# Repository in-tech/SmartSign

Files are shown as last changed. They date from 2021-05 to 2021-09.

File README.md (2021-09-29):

# SmartSign
A battery powered e-Paper sign for conference rooms.

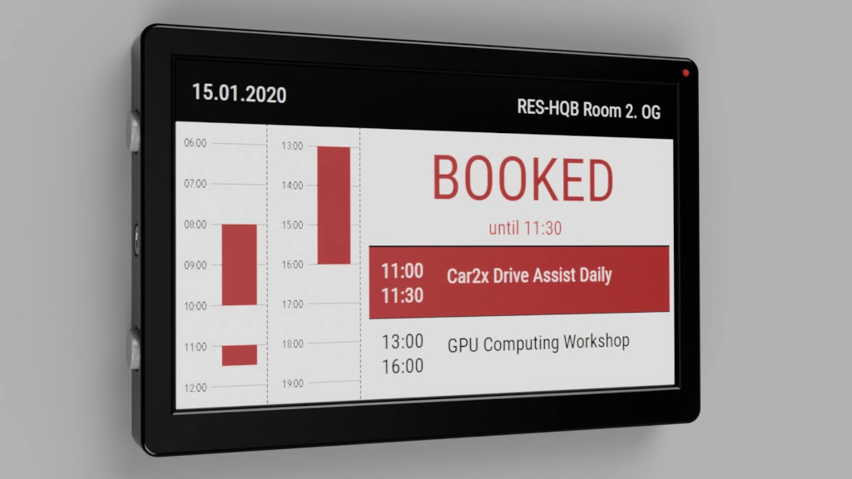
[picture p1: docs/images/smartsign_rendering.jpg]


## Device-Frame
The shell components are optimized for FDM printing in PLA with 0.2 mm layer height.

STL-files:
* [Backplate.stl](stl_files/Backplate.stl)
* [ButtonSpacer.stl](stl_files/ButtonSpacer.stl)
* [Frame.stl](stl_files/Frame.stl)
* [Inlay.stl](stl_files/Inlay.stl)

## Electronics
The hardware is based on of the shelf components and requires no custom PCB designs:
* DFRobot FireBeetle ESP32 IOT Microcontroller
* Waveshare 7.5inch e-Paper B V1 (640x384)
* 3000 mAh LiPo Battery
* RFID RC522 Reader to read Mifare S50 keycards for administration and authorization
* Mechanical endstop to wake ESP when card is inserted
* 3mm red LED with 47µF Capacitor and N-Channel FET to keep LED state when ESP is in deep sleep
* 2x tactile switch buttons (12x12x7.3mm)
* Resistors: 1x 330 Ohm, 3x 22K-Ohm, 1x 32K-Ohm, 2x 100K-Ohm
  
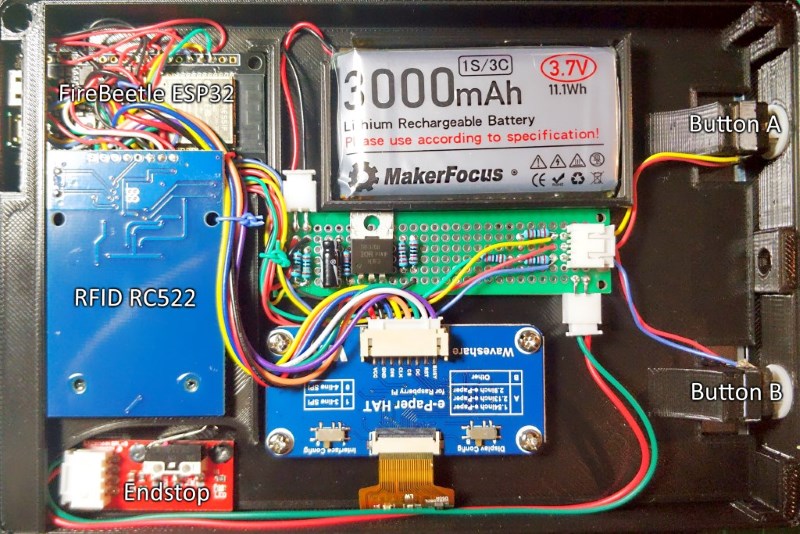
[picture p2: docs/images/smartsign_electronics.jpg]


How the components are interconnected, is documented here: [smartsign_schematic.pdf](docs/smartsign_schematic.pdf)

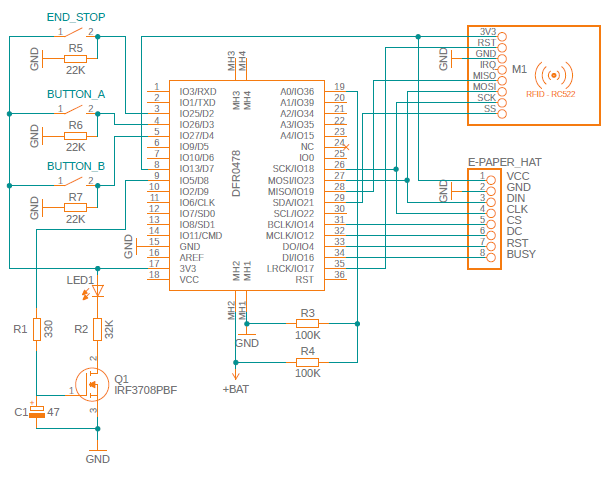
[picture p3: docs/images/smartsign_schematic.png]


## Firmware
The firmware is written in C++ and based on PlatformIO. Before you can build the project, you have to create a settings file by renaming the file [`.\lib\SmartSign\GlobalSettings.h.default`](lib/SmartSign/GlobalSettings.h.default) to `.\lib\SmartSign\GlobalSettings.h`. 

In `GlobalSettings.h` change the `ADMIN_CARD_ID` value to match the id of the keycard you want to use to enter the administration mode. All other parameters in this file are default values and can be changed during runtime in the setup mode via web-interface.

## Administration-Mode
You can enter the administration mode, by inserting the **administration keycard** into the cardslot:

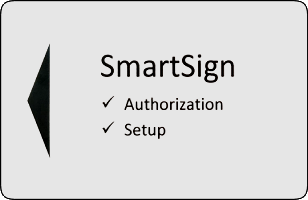
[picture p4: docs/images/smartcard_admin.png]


The administration screen provides information about the current battery voltage, WiFi status and NTP time. When the battery voltage falls below 3.6 volt you should consider recharging the device.

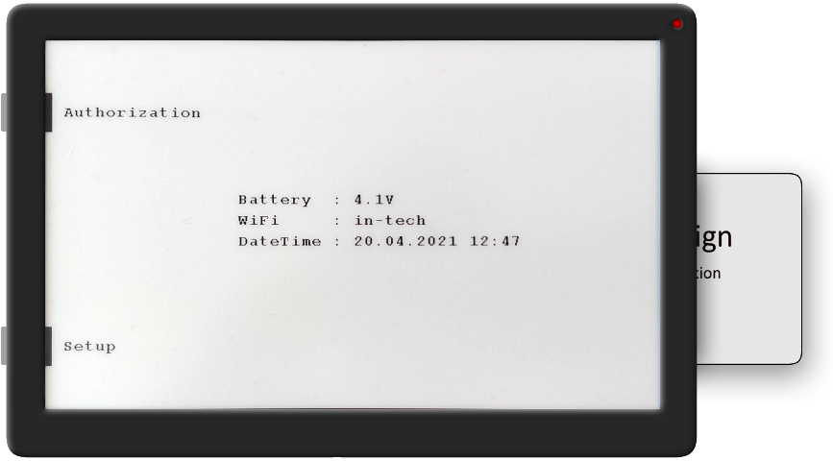
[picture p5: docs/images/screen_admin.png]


## Setup-Mode
You can enter the setup mode by pressing button B in the administration mode. In this mode, the SmartSign creates a temporary WiFi hotspot with a random name and random password. Whe connecting to this WiFi with your smartphone or computer, you gain access to a property page where you can change the settings specified in [`.\lib\SmartSign\GlobalSettings.h`](lib/SmartSign/GlobalSettings.h.default). The most important settings are the WiFi credentials, the name of the schedule and the Azure client and tenant ids (more on this [here](https://docs.microsoft.com/en-us/graph/tutorials/dotnet-core?view=graph-rest-beta&tutorial-step=2)). 

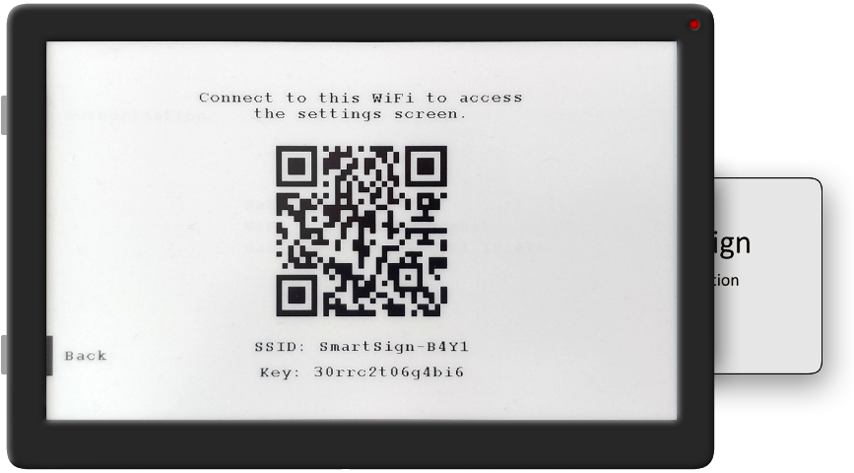
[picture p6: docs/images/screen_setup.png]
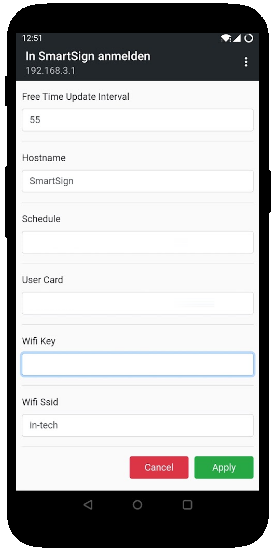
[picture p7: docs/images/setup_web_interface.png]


## Authorization-Mode
Before the SmartSign can show schedules of your outlook calendar, you have to authorize the device to access you calendar. You can enter the authorization mode from the administration mode by pressing button A. Another way to enter the authorization mode is to insert a card that is dedicated to enter this mode. You can configure this option by setting the **User Card** in the setup mode.

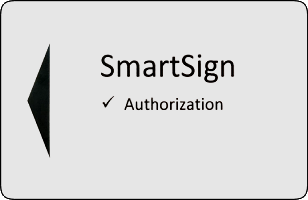
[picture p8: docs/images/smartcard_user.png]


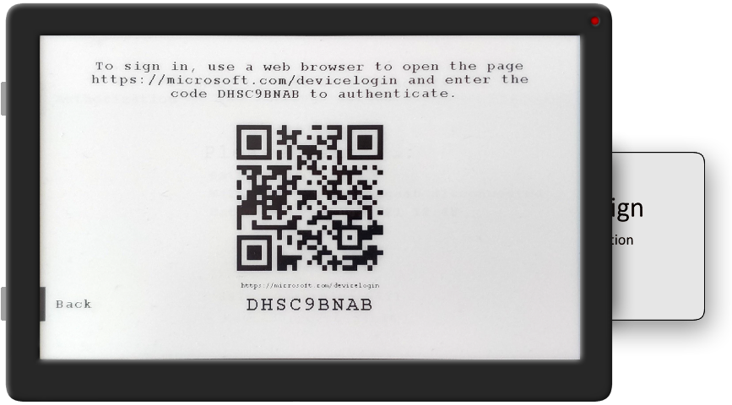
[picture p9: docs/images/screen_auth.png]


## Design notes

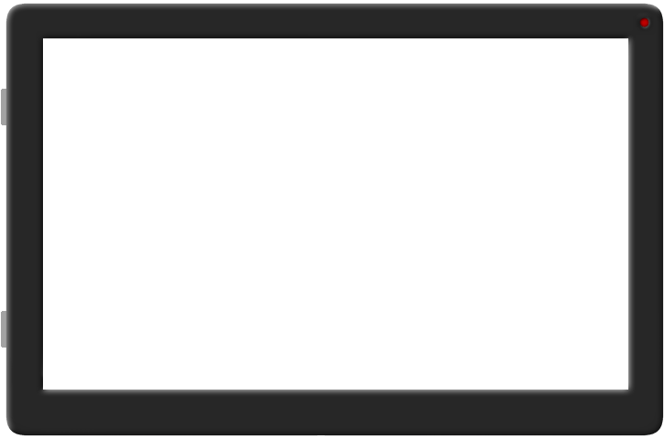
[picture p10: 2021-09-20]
docs/images/frame_led_on.png

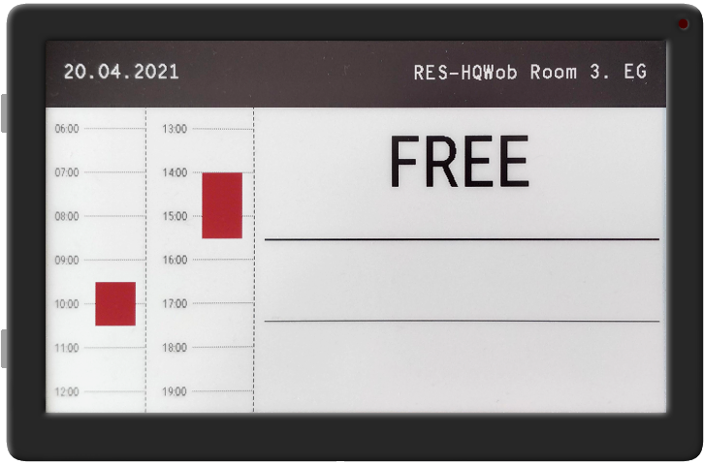
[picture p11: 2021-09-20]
docs/images/screen_free.png

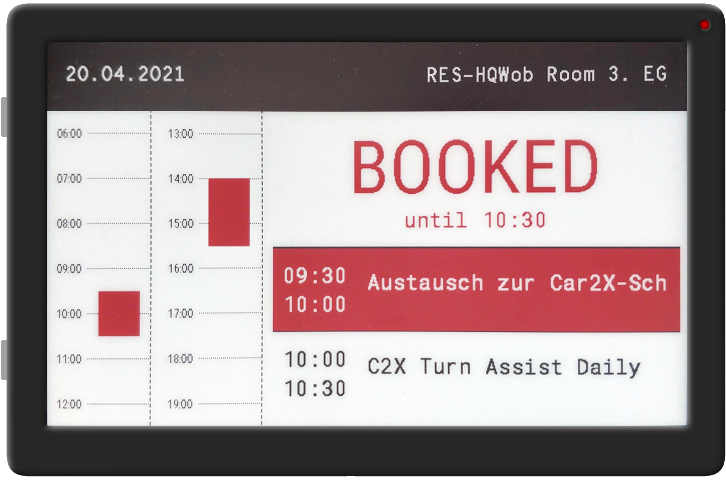
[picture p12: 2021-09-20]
docs/images/screen_booked.png

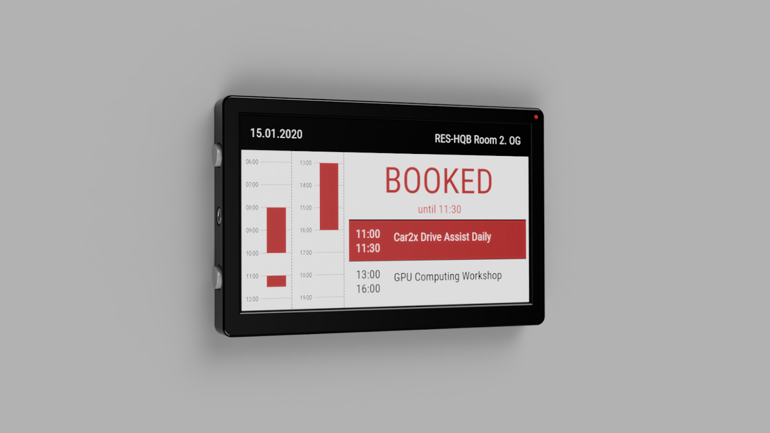
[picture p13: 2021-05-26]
docs/images/smartsign_rendering.png

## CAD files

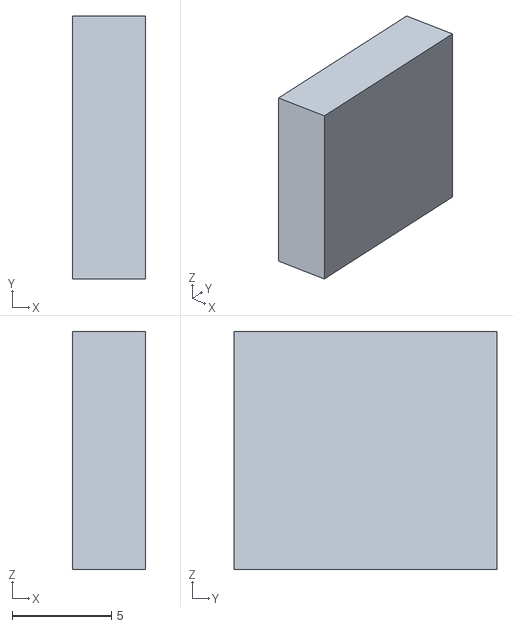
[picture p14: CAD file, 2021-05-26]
stl_files/ButtonSpacer.stl
3.70 x 13.2 x 12.0

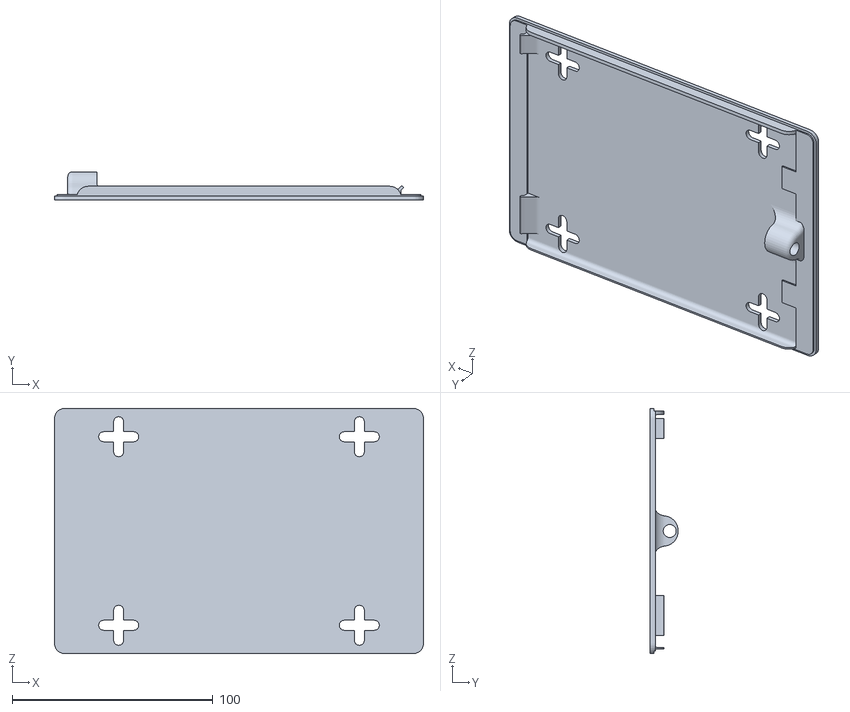
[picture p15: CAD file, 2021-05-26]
stl_files/Backplate.stl
184.0 x 14.2 x 122.2

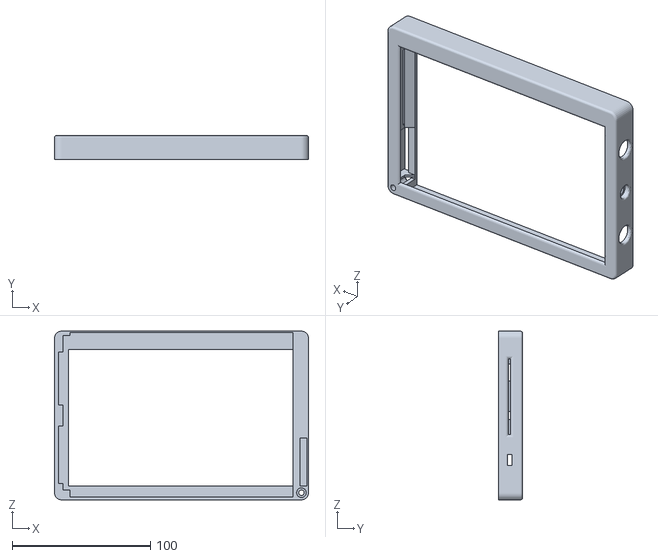
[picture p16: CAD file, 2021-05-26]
stl_files/Frame.stl
184.0 x 17.4 x 122.2

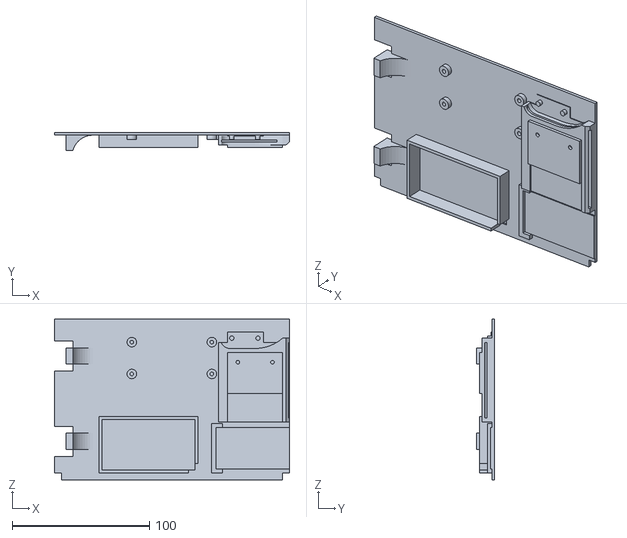
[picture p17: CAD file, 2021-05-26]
stl_files/Inlay.stl
171.2 x 13.2 x 117.0

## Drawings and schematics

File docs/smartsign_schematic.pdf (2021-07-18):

A

A

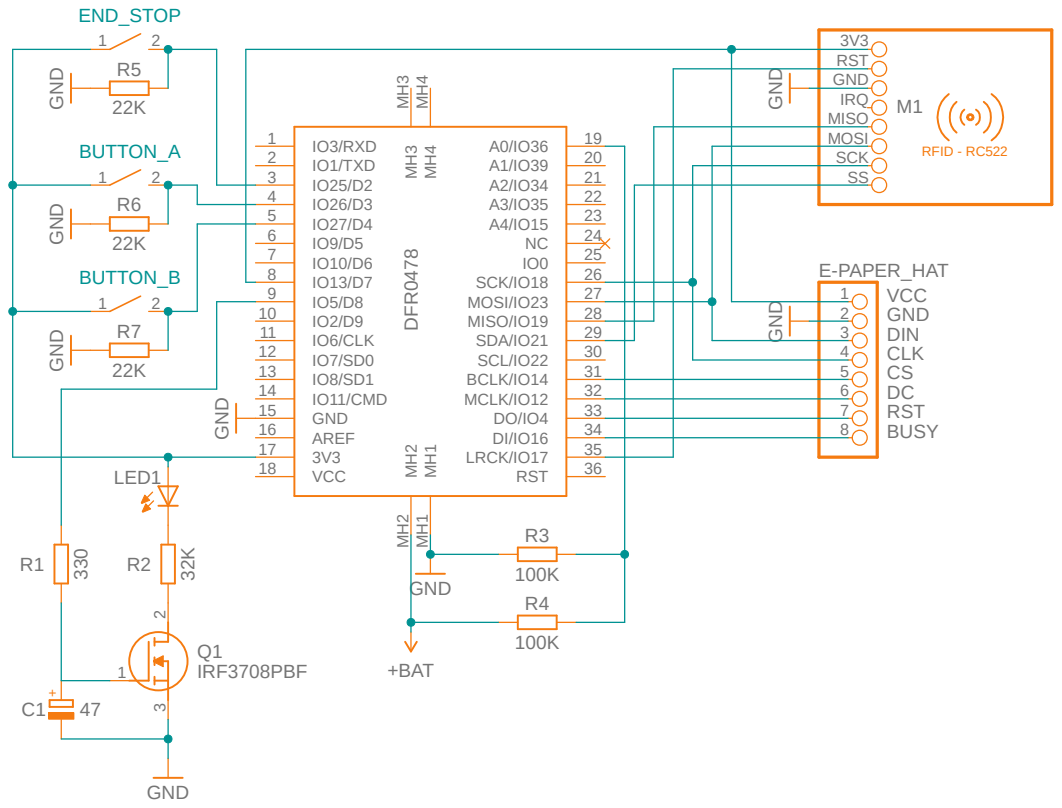
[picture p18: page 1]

RST
GND

GND GND GND IO3/RXD

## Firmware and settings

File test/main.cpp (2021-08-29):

#include "AsciiCompressorTests.hpp"
#include "PowerTests.hpp"
#include "InputTests.hpp"
#include "LedTests.hpp"
#include "DisplayTests.hpp"

void setup()
{
    delay(2000);

    UNITY_BEGIN();

    RUN_TEST(ascii_compressor_tests::test_compression_decompression);

    RUN_TEST(power_tests::test_battery_voltage);

    RUN_TEST(input_tests::test_button_A);
    RUN_TEST(input_tests::test_button_B);

    RUN_TEST(led_tests::test_blink_led);

    RUN_TEST(input_tests::test_smart_card_reader_end_stop);
    RUN_TEST(input_tests::test_smart_card_id);

    RUN_TEST(display_tests::test_info_message);
    RUN_TEST(display_tests::test_font_rendering);
    RUN_TEST(display_tests::test_booked_schedule_screen);
    RUN_TEST(display_tests::test_free_schedule_screen);

    UNITY_END();
}

void loop()
{
}

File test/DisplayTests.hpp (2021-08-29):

#pragma once
#include <Arduino.h>
#include <unity.h>
#include "Display.h"
#include "AppContextMock.hpp"

namespace display_tests
{
    class AppContextDisplayMock : public AppContextMock1
    {
    public:
        AppContextDisplayMock()
            : _display(*this)
        {
        }

        IDisplay &GetDisplay() { return _display; };

        void Init()
        {
            AppContextMock1::Init();
            _display.Init();
        };

        void DeInit()
        {
            AppContextMock1::DeInit();
            _display.DeInit();
        }

    private:
        Display _display;
    };

    bool wait_for_button_press(IAppContext &ctx, const bool btn_a, const bool btn_b, const unsigned long timeout_secs)
    {
        unsigned long start = millis();
        while ((millis() - start) < timeout_secs * 1000)
        {
            if (ctx.GetDisplay().IsBusy())
            {
                start = millis();
            }

            auto inputState = ctx.GetInputMgr().State();
            if (inputState.PressedButtonA == btn_a && inputState.PressedButtonB == btn_b)
            {
                return true;
            }
            delay(10);
            ctx.Update();
        }
        return false;
    }

    void test_info_message()
    {
        AppContextDisplayMock ctx;
        ctx.Init();
        ctx.GetDisplay().ShowInfoScreen("display_tests::test_info_message", "Button A", "Button B");
        ctx.Update();

        Serial.println("Please press button A if you can read the message 'display_tests::test_info_message' on the display.");
        bool success = wait_for_button_press(ctx, true, false, 10);
        TEST_ASSERT_TRUE(success);
    }

    void test_font_rendering()
    {
        AppContextDisplayMock ctx;
        ctx.Init();
        ctx.GetDisplay().ShowFontTestScreen();
        ctx.Update();

        Serial.println("Please press button A if font rendering looks all right on the display.");
        bool success = wait_for_button_press(ctx, true, false, 10);
        TEST_ASSERT_TRUE(success);
    }

    void test_booked_schedule_screen()
    {
        AppContextDisplayMock ctx;
        ctx.Init();

        time_t utcNow = TimeUtils::UtcIsoStringToTime("2021-04-01T09:52:00");
        time_t localNow = utcNow;
        std::vector<ScheduleItem> items;
        {
            ScheduleItem item = {};
            item.Subject = "Heinz, Karl";
            item.LocalStartTime = TimeUtils::UtcIsoStringToTime("2021-04-01T06:30:00");
            item.LocalEndTime = TimeUtils::UtcIsoStringToTime("2021-04-01T06:35:00");
            items.push_back(item);
        }

        {
            ScheduleItem item = {};
            item.Subject = "Wurst, Hans";
            item.LocalStartTime = TimeUtils::UtcIsoStringToTime("2021-04-01T07:30:00");
            item.LocalEndTime = TimeUtils::UtcIsoStringToTime("2021-04-01T10:00:00");
            items.push_back(item);
        }

        {
            ScheduleItem item = {};
            item.Subject = "Mustermann, Max 0123456789ABCDEF";
            item.LocalStartTime = TimeUtils::UtcIsoStringToTime("2021-04-01T10:00:00");
            item.LocalEndTime = TimeUtils::UtcIsoStringToTime("2021-04-01T14:30:00");
            items.push_back(item);
        }

        {
            ScheduleItem item = {};
            item.Subject = "Roßbach, Marc";
            item.LocalStartTime = TimeUtils::UtcIsoStringToTime("2021-04-01T15:00:00");
            item.LocalEndTime = TimeUtils::UtcIsoStringToTime("2021-04-01T16:00:00");
            items.push_back(item);
        }

        ctx.GetDisplay().ShowScheduleScreen(localNow, items);

        Serial.println("Please press button A if BOOKED schedule looks all right on the display.");
        bool success = wait_for_button_press(ctx, true, false, 10);
        TEST_ASSERT_TRUE(success);
    }

    void test_free_schedule_screen()
    {
        AppContextDisplayMock ctx;
        ctx.Init();

        time_t utcNow = TimeUtils::UtcIsoStringToTime("2021-04-01T09:52:00");
        time_t localNow = utcNow;
        std::vector<ScheduleItem> items;

        {
            ScheduleItem item = {};
            item.Subject = "Mustermann, Max 0123456789ABCDEF";
            item.LocalStartTime = TimeUtils::UtcIsoStringToTime("2021-04-01T10:00:00");
            item.LocalEndTime = TimeUtils::UtcIsoStringToTime("2021-04-01T14:30:00");
            items.push_back(item);
        }

        ctx.GetDisplay().ShowScheduleScreen(localNow, items);

        Serial.println("Please press button A if FREE schedule looks all right on the display.");
        bool success = wait_for_button_press(ctx, true, false, 10);
        TEST_ASSERT_TRUE(success);
    }
}

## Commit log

2021-07-18 docs: add electronic schematics
2021-08-29 test: add unit tests for display, buttons, led and card reader
2021-08-29 test: add battery voltage test
2021-08-29 fix: increase time for fast display refresh to fix issues in low temperature environments
2021-09-17 docs: add 3d print and build instructions to readme
2021-09-17 docs: update schematic
